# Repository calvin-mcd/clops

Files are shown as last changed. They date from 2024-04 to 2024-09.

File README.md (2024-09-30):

# clops

clops is a qazlike unibody split sub40s keyboard. The KLE and firmware is by ha ha ha which itself is inspired by a [KLE](http://www.keyboard-layout-editor.com/#/gists/c3c008118662d8631bc35f2af838a2c1) from [Noelle](https://github.com/fivedee). PCB is designed by Calvin0563. It sports a rp2040 and hotswap socket, and supports 1 center rotary encoder and 1 bottom row roller encoder.

## Layout

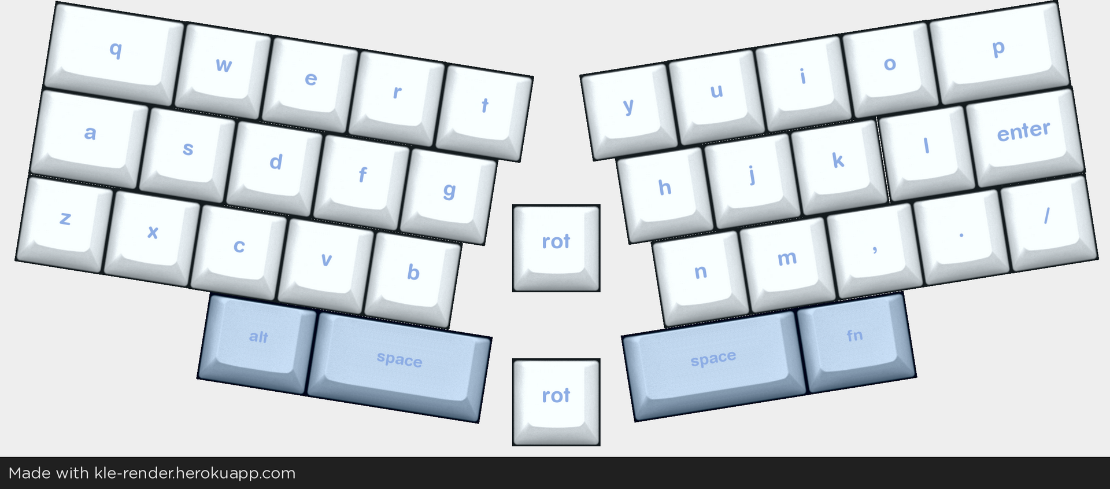
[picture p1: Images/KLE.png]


[Link](http://www.keyboard-layout-editor.com/#/gists/6cb4f40dfc184b6e9601f9cb672765c0)

## Pictures

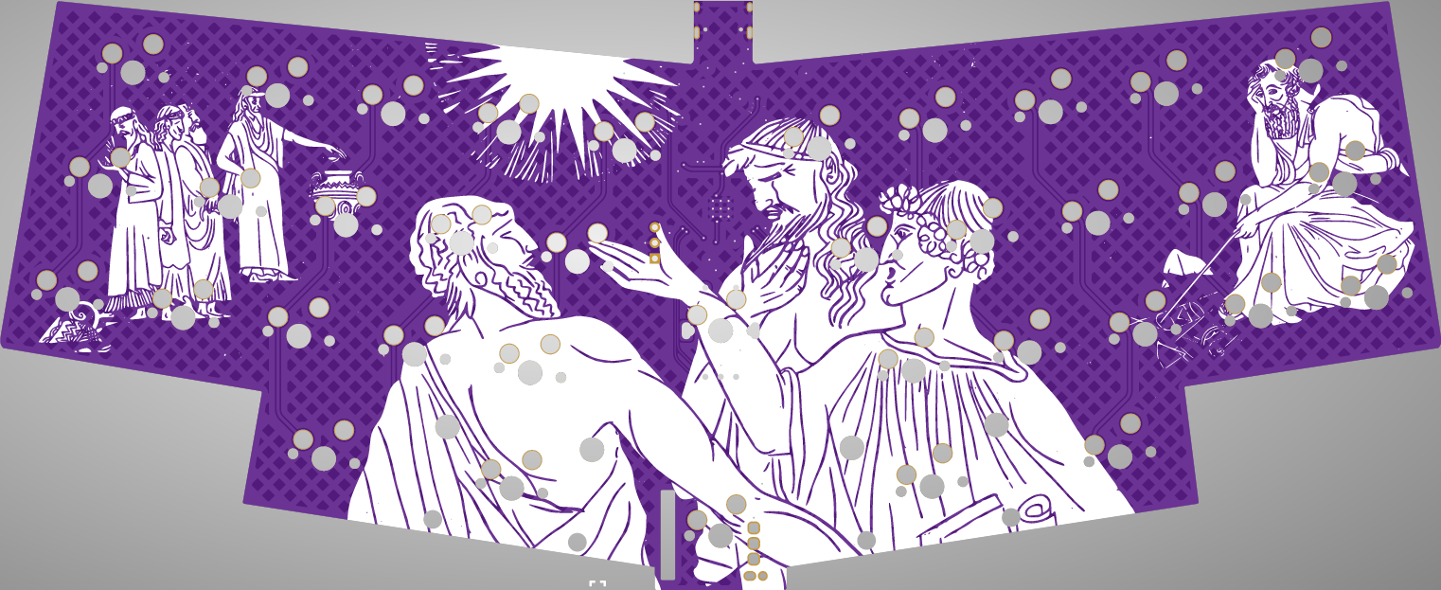
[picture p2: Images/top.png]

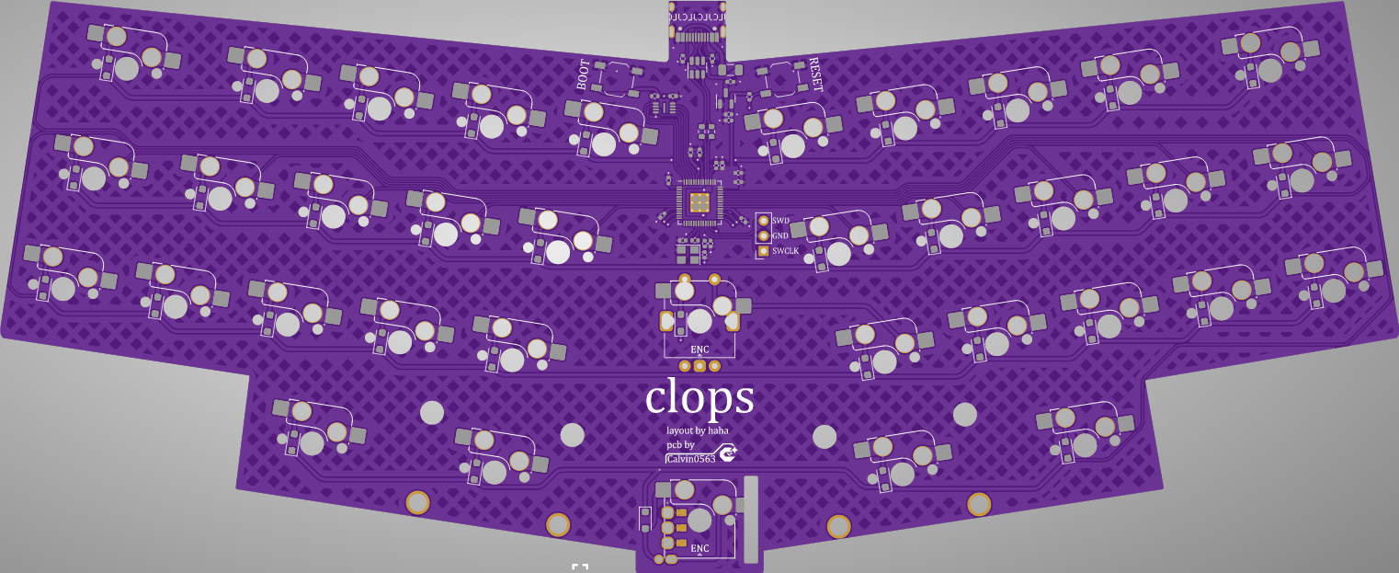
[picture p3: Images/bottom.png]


## Build Guide

When installing the Roller encoder be sure to remove the plastic clips where the encoder slots into the pcb cut out and make sure it is aligned to your satisfaction with the centre of the pcb before soldering!

## Firmware

The firmware was written by ha ha ha and both the flash file and source code can be found in the firmware folder.

## Case

[protieusz](https://github.com/protieusz) has designed a 3d printable case for the clops. It can be found here:

https://github.com/protieusz/CyKlops-Case/tree/main

Make sure to check out all their other cool keyboard projects on their github!

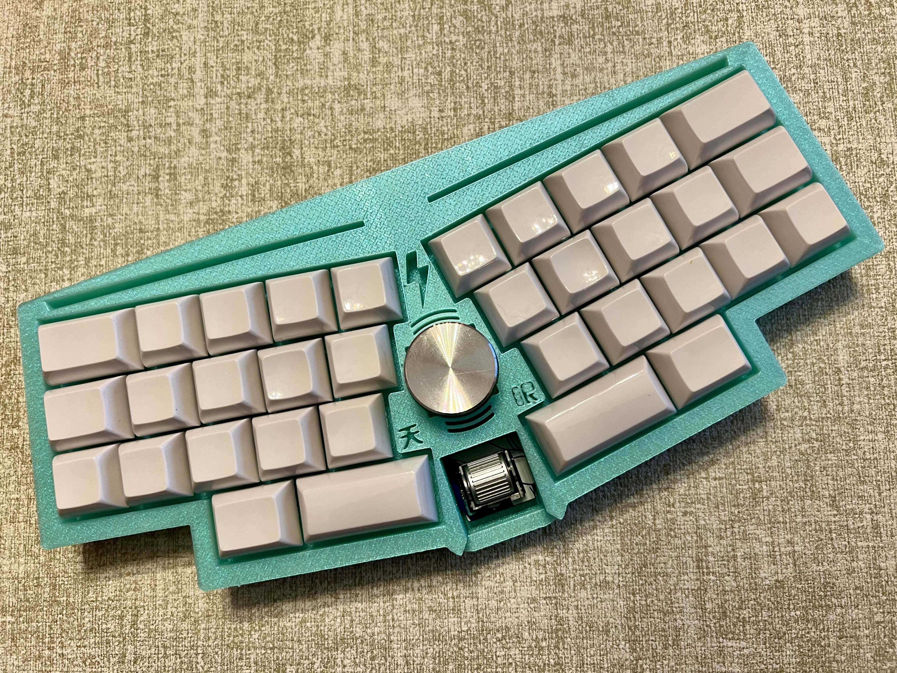
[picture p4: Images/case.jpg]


## Disclaimer

This PCB has been fully tested and is confirmed to work. However, no-one involved in this project is responsible for any usage issues that may arise. Order at your own risk. Feel free to edit, modify and otherwise utilise these files.

## License

This project is released under the GPL v3 License. Please refer to the LICENCE file.

## Credits

Big thanks to ha ha ha and protieusz and all the many people who helped me and inspired this board!

Any questions, contact Calvin0563 on Discord.

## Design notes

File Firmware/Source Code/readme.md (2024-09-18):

# clops

lucky

_A short description of the keyboard/project_

-   Keyboard Maintainer: [ha ha ha](https://github.com/zackforbing)
-   Hardware Supported: _The PCBs, controllers supported_
-   Hardware Availability: _Links to where you can find this hardware_

Make example for this keyboard (after setting up your build environment):

    make clops:default

Flashing example for this keyboard:

    make cloips:default:flash

See the [build environment setup](https://docs.qmk.fm/#/getting_started_build_tools) and the [make instructions](https://docs.qmk.fm/#/getting_started_make_guide) for more information. Brand new to QMK? Start with our [Complete Newbs Guide](https://docs.qmk.fm/#/newbs).

## Bootloader

Enter the bootloader in 3 ways:

-   **Bootmagic reset**: Hold down the key at (0,0) in the matrix (usually the top left key or Escape) and plug in the keyboard
-   **Physical reset button**: Briefly press the button on the back of the PCB - some may have pads you must short instead
-   **Keycode in layout**: Press the key mapped to `QK_BOOT` if it is available

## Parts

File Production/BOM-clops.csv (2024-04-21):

Comment | Designator | Footprint | LCSC
boot | SW4,SWR1 | SW_SPST_TL3342 | C115351
1k | R7 | R_0402_1005Metric | C11702
100nF | C10,C11,C12,C13,C14,C15,C18,C5,C6,C9 | C_0402_1005Metric | C1525
10uF | C7 | C_0402_1005Metric | C15525
22pF | C2,C3 | C_0402_1005Metric | C1555
USB_C_Receptacle_USB2.0 | J1 | USB_C_Receptacle_HRO_TYPE-C-31-M-12 | C165948
RP2040 | U3 | RP2040-QFN-56 | C2040
27R | R5,R6 | R_0603_1608Metric | C25190
1k | R9 | R_0402_1005Metric | C25543
5.1k | R1,R3,R4 | R_0402_1005Metric | C25905
USBLC6-2SC6 | U2 | SOT-23-6 | C2827654
W25Q16JVUXIQ | IC1 | SON50P300X200X60-9N | C2843335
MX_SW_HS | MX1,MX10,MX11,MX12,MX13,MX14,MX15,MX16,MX17,MX18,MX19,MX2,MX20,MX21,MX22,MX23,MX24,MX25,MX26,MX27,MX28,MX29,MX3,MX30,MX31,MX32,MX33,MX34,MX35,MX36,MX4,MX5,MX6,MX7,MX8,MX9 | SW_MX_HS_CPG151101S11_1.5u | C5156480
1uF | C16,C17,C4,C8 | C_0402_1005Metric | C52923
XC6206PxxxMR-Regulator_Linear | U4 | SOT-23 | C5446
500mA | F1 | Fuse_1206_3216Metric | C70076
D_Small | D1,D10,D11,D12,D13,D14,D15,D16,D17,D18,D19,D2,D20,D21,D22,D23,D24,D25,D26,D27,D28,D29,D3,D30,D31,D32,D33,D34,D35,D36,D4,D5,D6,D7,D8,D9 | D_SOD-123F | C81598
12MHz | Y1 | Crystal_SMD_3225-4Pin_3.2x2.5mm | C9002

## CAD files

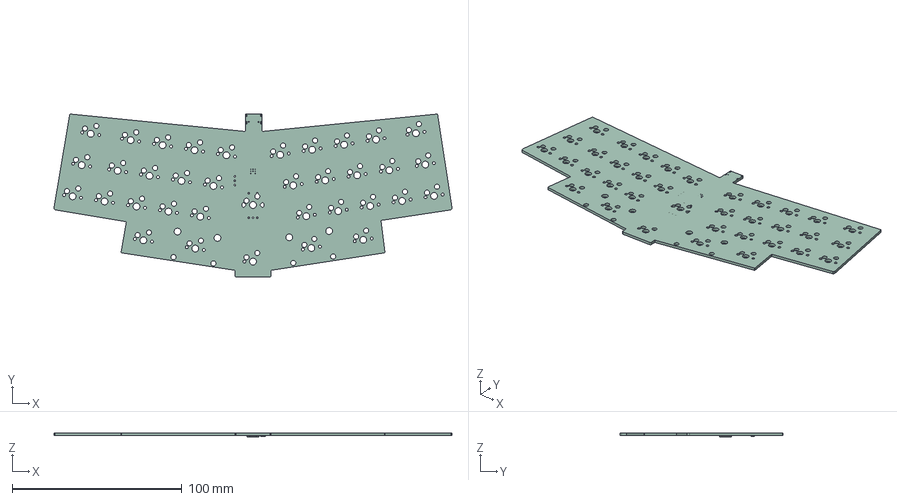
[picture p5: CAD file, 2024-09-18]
Project/clops.step
234.5 x 96.0 x 2.65 mm
W25X40CLUXIG TR
RP2040_QFN_PACKAGE
_autosave-clops_PCB

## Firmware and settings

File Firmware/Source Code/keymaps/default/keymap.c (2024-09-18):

// Copyright 2023 QMK
// SPDX-License-Identifier: GPL-2.0-or-later

#include QMK_KEYBOARD_H

const uint16_t PROGMEM keymaps[][MATRIX_ROWS][MATRIX_COLS] = {

[0] = LAYOUT(
        KC_Q,   KC_W,   KC_E,   KC_R,   KC_T,               KC_Y,       KC_U,       KC_I,       KC_O,   KC_P,
        KC_A,   KC_S,   KC_D,   KC_F,   KC_G,   KC_CAPS,    KC_H,       KC_J,       KC_K,       KC_L,   KC_SCLN,
        KC_Z,   KC_X,   KC_C,   KC_V,   KC_B,               KC_N,       KC_M,       KC_COMM,    KC_DOT, KC_SLSH,
                                KC_TAB, KC_SPC, KC_MPLY,    KC_BSPC,    KC_DEL
            )
};

#if defined(ENCODER_MAP_ENABLE)
const uint16_t PROGMEM encoder_map[][NUM_ENCODERS][2] = {
    [0] =   { ENCODER_CCW_CW(KC_MS_WH_UP, KC_MS_WH_DOWN), ENCODER_CCW_CW(KC_VOLD, KC_VOLU)  },
    //                  Encoder 1                                     Encoder 2
};
#endif

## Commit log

2024-04-21 changed roller switch set up
    [CPL-clops.csv, clops-B_Cu.gbr, clops-B_Mask.gbr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]
2024-09-18 added hahaha's firmware
    [clops.step]
2024-09-20 revision 1.1
    roller encoder positioning
    firmware update
    [clops-B_Cu.gbr, clops-B_Mask.gbr, clops-B_Paste.gbr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]
2024-09-21 Revert "update"
    This reverts commit de9b7cebc370d770c1946fd24c0ccf0d0e181036.
    [clops.kicad_sch]
2024-09-21 Revert "revision 1.1"
    This reverts commit f2d166f1cd0ace3f6bfa130c7dff299d4c7fad9e.
    [clops-B_Cu.gbr, clops-B_Mask.gbr, clops-B_Paste.gbr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]
2024-09-30 case update
